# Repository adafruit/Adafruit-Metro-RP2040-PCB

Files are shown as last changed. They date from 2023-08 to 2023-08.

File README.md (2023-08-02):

## Adafruit Metro RP2040 PCB

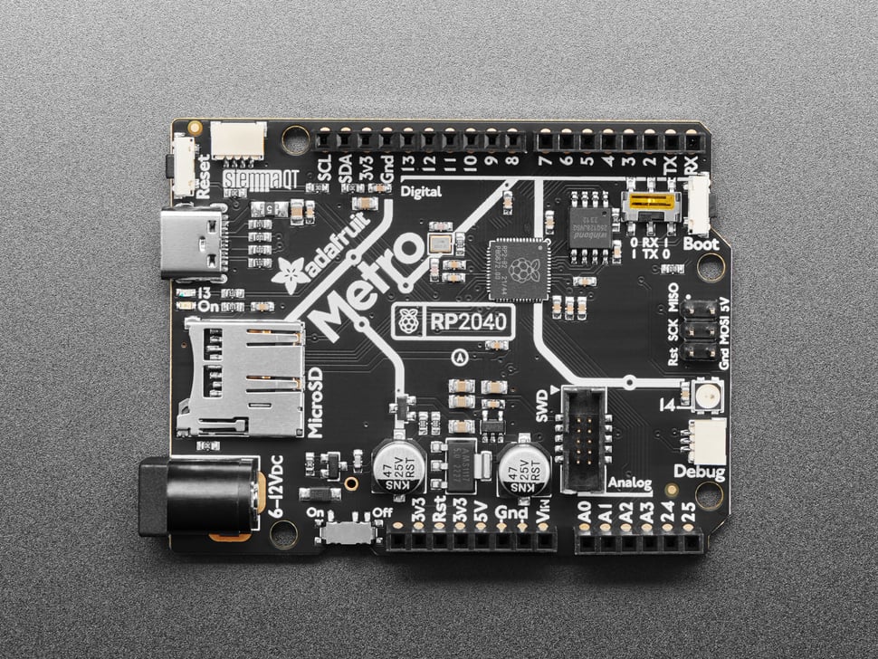
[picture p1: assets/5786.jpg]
<a href="http://www.adafruit.com/products/5786"><br/>
Click here to purchase one from the Adafruit shop</a>

PCB files for the Adafruit Metro RP2040. 

Format is EagleCAD schematic and board layout
* https://www.adafruit.com/product/5786

### Description

Choo! Choo! This is the RP2040 Metro Line, making all station stops at "Dual Cortex M0+ mountain", "264K RAM round-about" and "16 Megabytes of Flash town". This train is pile high with hardware that complements the Raspberry Pi RP2040 chip to make it an excellent development board for projects that want Arduino-shape-compatibility or just need the extra space and debugging ports.

* RP2040 main chip, 133MHz clock, 3.3V logic
* 16 MB of QSPI flash for program storage
* 24 GPIO, 4 of which are also analog inputs
* Micro SD card wired up for SPI interfacing, also has extra pins connected for advanced-user SDIO interfacing (note that there's no released usage code for SDIO in Arduino/Python, so this is a super-cutting-edge setup)
* Onboard RGB NeoPixel
* Onboard #13 LED
* Stemma QT port for I2C peripherals and sensors
* Reset and Boot buttons on PCB edge
* Pico Probe debug port - 3 pin JST SH compatible
* SWD debug port - 2x5 0.05" standard connector
* USB Type C power and data
* 5.5mm / 2.1mm DC jack for 6-12VDC power
* On/off switch for DC jack
* GPIO pin numbers match classic Arduino pins, other than A4/A5 which are D24 and D25 (there's only 4 ADC pins on the RP2040)
* RX / TX switch for swapping D0 and D1 locations

You may be wondering about the RX-TX switch: we added this because traditional Arduino board start counting the GPIO for the digital pins with 0-7 and then 8-13. However, the D0/D1 pins are also traditionally the hardware UART Serial1, where D0 is Rx and D1 is Tx. On the RP2040, however, the UART pins are the other around: D0 is Tx and D1 is Rx. Thus a DPDT switch: flip one way to have the GPIO go in order of 0-7, flip the other way to have the logical locations of the hardware UART correct but now the pin order is 1, 0, 2, 3..7. Of course, it's also handy if, like us, you often swap the pins - now you don't need to require or cut/solder traces!
About the RP2040

The RP2040 is a powerful chip, which has the clock speed of our M4 (SAMD51), and two cores that are equivalent to our M0 (SAMD21). Since it is an M0 chip, it does not have a floating point unit or DSP hardware support - so if you're doing something with heavy floating-point math, it will be done in software and thus not as fast as an M4. For many other computational tasks, you'll get close-to-M4 speeds!

For peripherals, there are two I2C controllers, two SPI controllers, and two UARTs that are multiplexed across the GPIO - check the pinout for what pins can be set to which. There are 16 PWM channels, each pin has a channel it can be set to (ditto on the pinout).

You'll note there's no I2S peripheral, or SDIO, or camera, what's up with that? Well, instead of having specific hardware support for serial-data-like peripherals like these, the RP2040 comes with the PIO state machine system, which is a unique and powerful way to create custom hardware logic and data processing blocks that run on their own without taking up a CPU. For example, NeoPixels - often we bitbang the timing-specific protocol for these LEDs. For the RP2040, we instead use PIO object that reads in the data buffer and clocks out the right bitstream with perfect accuracy. Same with I2S audio in or out, LED matrix displays, 8-bit or SPI based TFTs, even VGA! In MicroPython and CircuitPython, you can create PIO control commands to script the peripheral and load it in at runtime. There are 2 PIO peripherals with 4 state machines each.

There is great C/C++ support, unofficial (but really good) Arduino support, an official MicroPython port, and a CircuitPython port! We, of course, recommend CircuitPython because we think it's the easiest way to get started, and it has support with most of our drivers, displays, sensors, and more, supported out of the box so you can follow along with our CircuitPython projects and tutorials.

While the RP2040 has lots of onboard RAM (264KB), it does not have built-in FLASH memory. Instead, that is provided by the external QSPI flash chip. On this board, there is 16 MB, which is shared between the program it's running and any file storage used by MicroPython or CircuitPython. When using C/C++, you get the whole flash memory, if using Python, you will have about 7 MB remaining for code, files, images, fonts, etc.
RP2040 Chip features:

* Dual ARM Cortex-M0+ @ 133MHz
* 264kB on-chip SRAM in six independent banks
* Support for up to 16MB of off-chip Flash memory via dedicated QSPI bus
* DMA controller
* Fully-connected AHB crossbar
* Interpolator and integer divider peripherals
* On-chip programmable LDO to generate core voltage
* 2 on-chip PLLs to generate USB and core clocks
* 30 GPIO pins, 4 of which can be used as analog inputs
* Peripherals
  * 2 UARTs
  * 2 SPI controllers
  * 2 I2C controllers
  * 16 PWM channels
  * USB 1.1 controller and PHY, with host and device support
  * 8 PIO state machines

### License

Adafruit invests time and resources providing this open source design, please support Adafruit and open-source hardware by purchasing products from [Adafruit](https://www.adafruit.com)!

Designed by Limor Fried/Ladyada for Adafruit Industries.

Creative Commons Attribution/Share-Alike, all text above must be included in any redistribution. 
See license.txt for additional details.

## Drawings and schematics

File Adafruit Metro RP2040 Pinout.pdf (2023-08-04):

# Adafruit Metro RP2040

# https://www.adafruit.com/product/5786

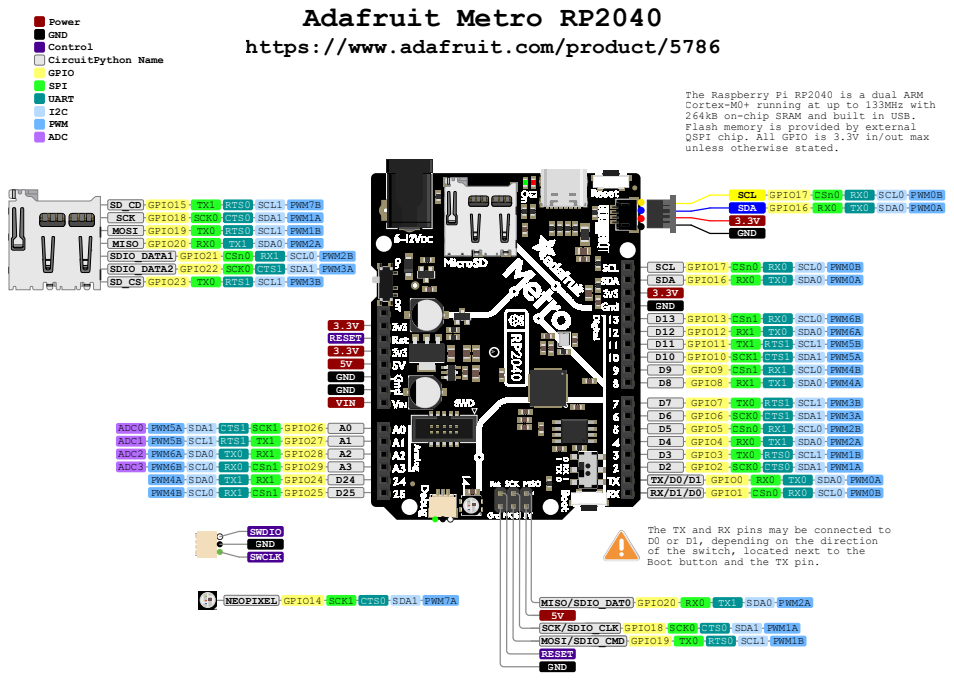
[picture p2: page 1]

The Raspberry Pi RP2040 is a dual ARM
Cortex-M0+ running at up to 133MHz with
264kB on-chip SRAM and built in USB.
Flash memory is provided by external
QSPI chip. All GPIO is 3.3V in/out max
unless otherwise stated.

The TX and RX pins may be connected to
D0 or D1, depending on the direction
of the switch, located next to the
Boot button and the TX pin.

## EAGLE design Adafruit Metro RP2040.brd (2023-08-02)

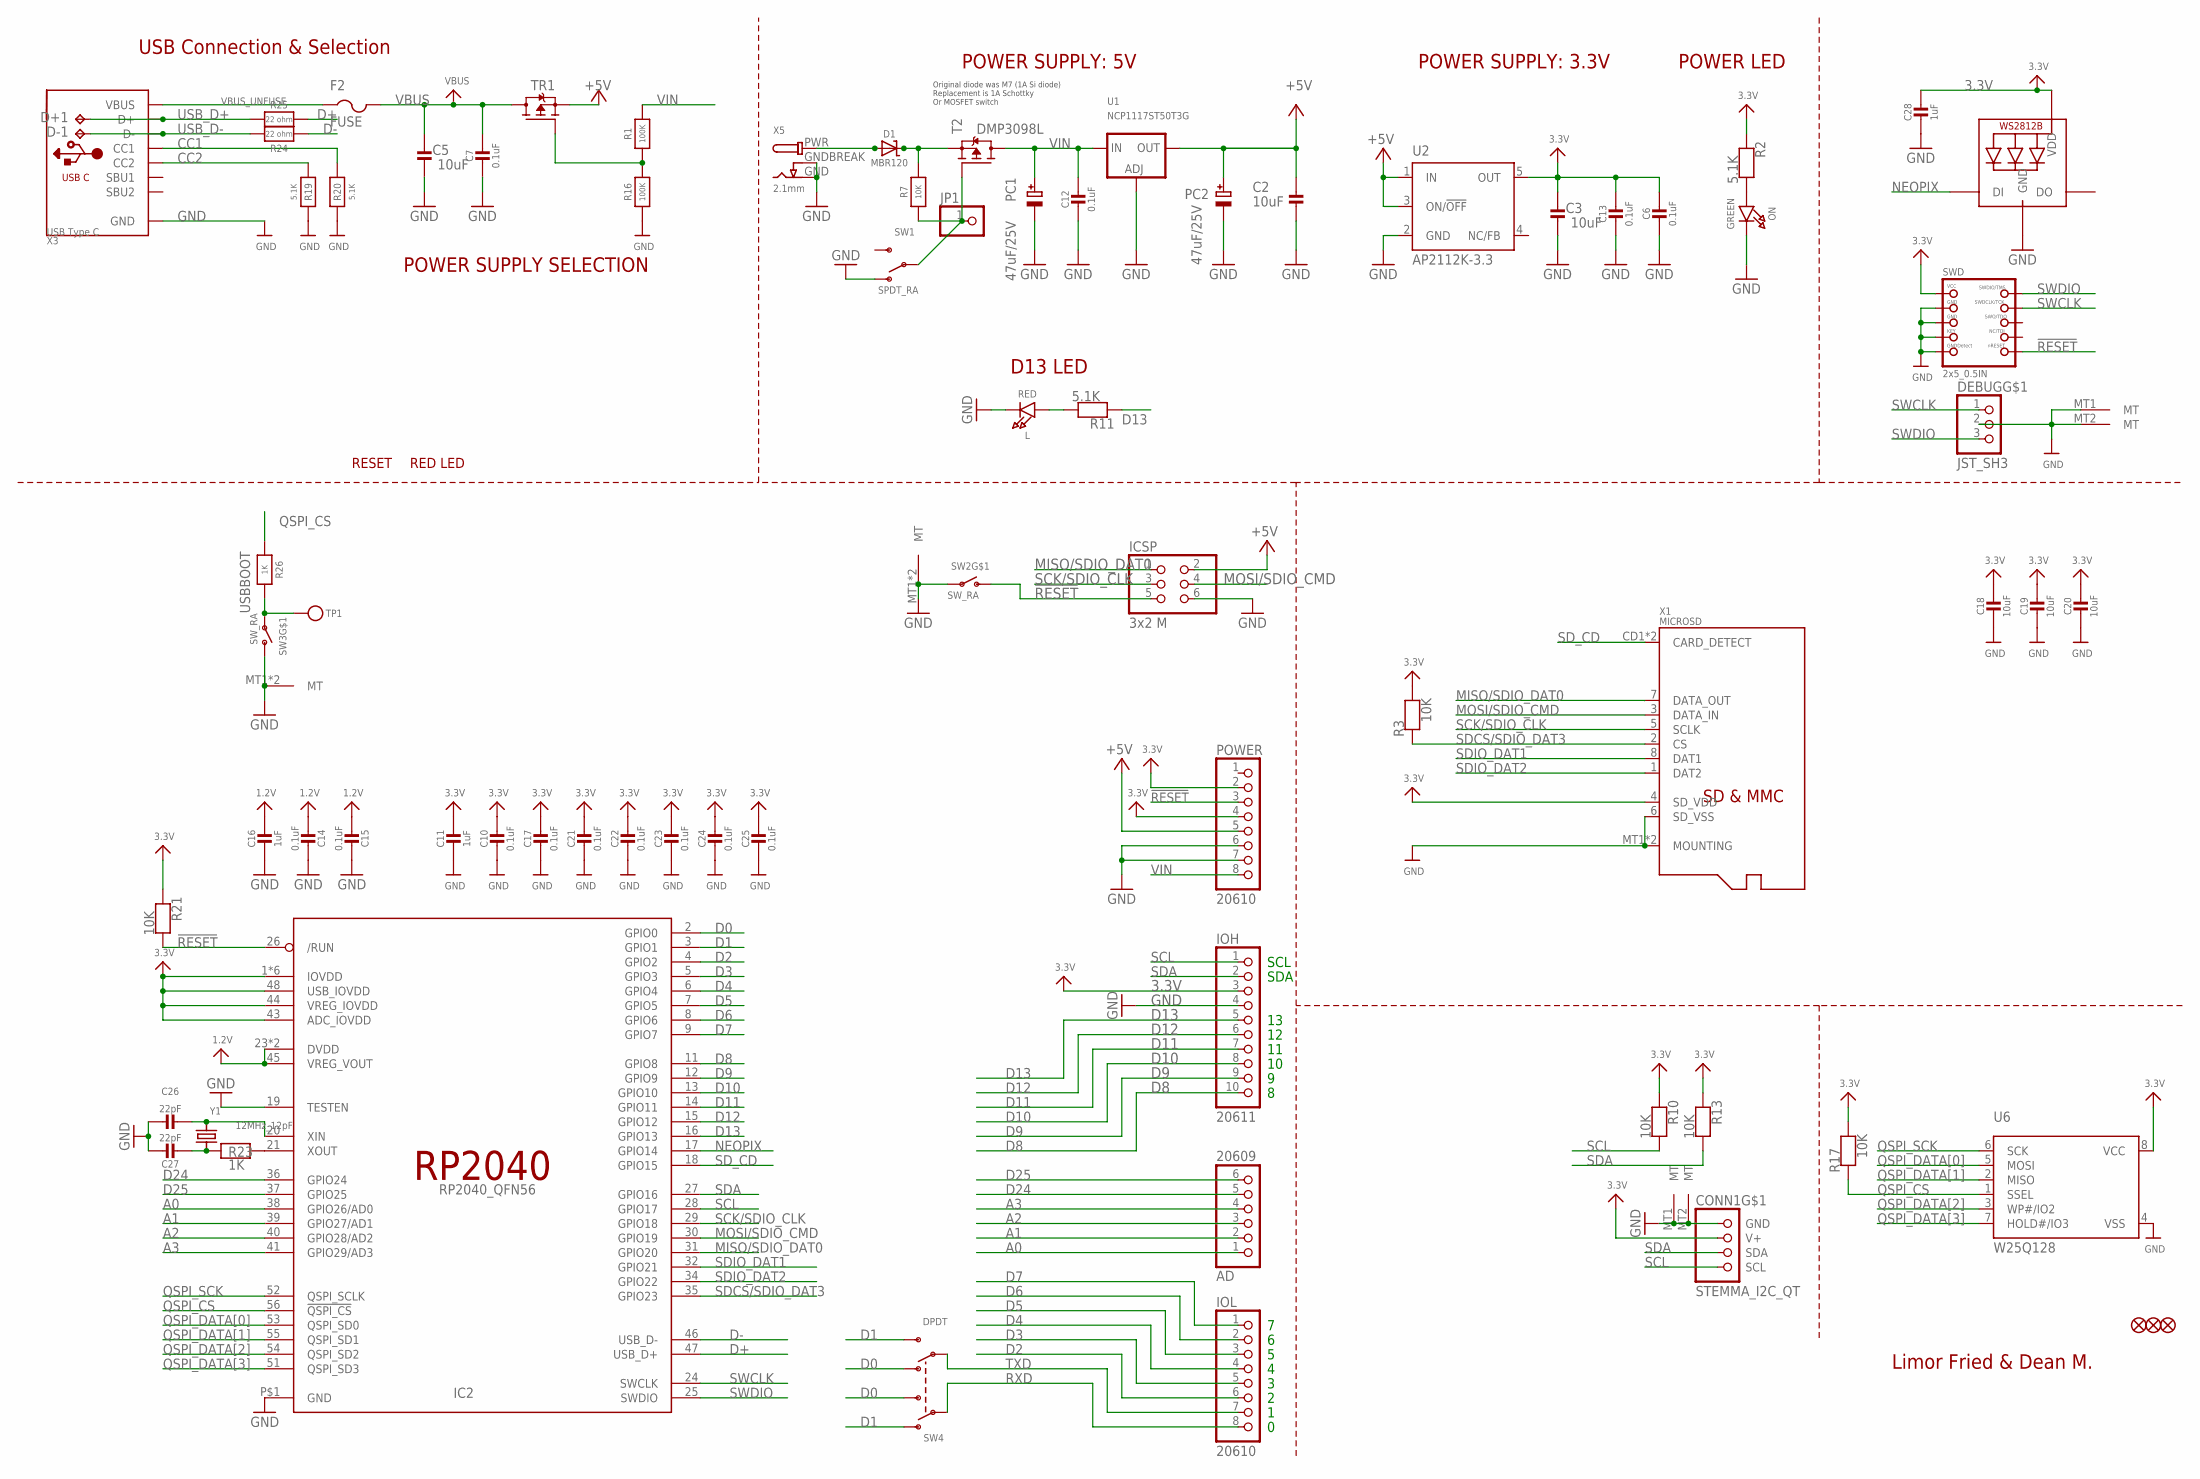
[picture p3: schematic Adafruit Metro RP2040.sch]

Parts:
AD: 20609; 1X06_OVALWAVE
C2, C3, C5, C18, C19, C20: 10uF; 0805-NO
C6, C7, C10, C12, C13, C14, C15, C17, C21, C22, C23, C24, C25: 0.1uF; 0603-NO
C11, C16, C28: 1uF; 0603-NO
C26, C27: 22pF; 0603-NO
CONN1: STEMMA_I2C_QT; JST_SH4
D1: MBR120; SOD-123
D+1: TPB1,27; B1,27
D-1: TPB1,27; B1,27
DEBUG: JST_SH3
F2: FUSE; R1206
FD1, FD2, FD3: FIDUCIAL_1MM
IC2: RP2040_QFN56; QFN56_7MM_REDUCEDEPAD
ICSP: 3x2 M; 2X03_ROUND_70MIL
IOH: 20611; 1X10_OVALWAVE
IOL: 20610; 1X08_OVALWAVE
JP1: HEADER-1X1ROUND; 1X01_ROUND
L: RED; CHIPLED_0603_NOOUTLINE
LED2: WS2812B_3535FULL; LED3535_FULLPADS
ON: GREEN; CHIPLED_0603_NOOUTLINE
PC1, PC2: 47uF/25V; PANASONIC_D
POWER: 20610; 1X08_OVALWAVE
R1, R16: 100K; 0603-NO
R2, R11, R19, R20: 5.1K; 0603-NO
R3, R7, R10, R13, R17, R21: 10K; 0603-NO
R23, R26: 1K; 0603-NO
R24, R25: 22 ohm; 0603-NO
SW1: SPDT_RA; SPDT_SMT_SSSS811101
SW2, SW3: SW_RA; SPST_TACTILE_RA
SW4: DPDT; EG1390
SWD: 2x5_0.5IN; 2X05_1.27MM_BOX_POSTS
T2: DMP3098L; SOT23-WIDE
TP1: TESTPOINTROUND1.5MMNO; TESTPOINT_ROUND_1.5MM_NO
TR1: DMP3098L; SOT23-WIDE
U1: NCP1117ST50T3G; SOT223-R
U2: AP2112K-3.3; SOT23-DBV
U6: W25Q128; SOIC8_208MIL
X1: MICROSD
X3: USB Type C; USB_C_CUSB31-CFM2AX-01-X
X5: 2.1mm; DCJACK_2MM_PTH
Y1: 12MHz_12pF; CRYSTAL_2.5X2

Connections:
1.2V: C14.2, C15.2, C16.1, IC2.23 (DVDD), IC2.45 (VREG_VOUT), IC2.50 (DVDD)
3.3V: C3.2, C6.2, C10.1, C11.1, C13.1, C17.1, C18.1, C19.1, C20.1, C21.1, C22.1, C23.1, C24.1, C25.1, C28.1, CONN1.2 (V+), IC2.1 (IOVDD), IC2.10 (IOVDD), IC2.22 (IOVDD), IC2.33 (IOVDD), IC2.42 (IOVDD), IC2.43 (ADC_IOVDD), IC2.44 (VREG_IOVDD), IC2.48 (USB_IOVDD), IC2.49 (IOVDD), IOH.3, LED2.2 (VDD), POWER.2, POWER.4, R2.1, R3.2, R10.1, R13.1, R17.2, R21.1, SWD.1 (VCC), U2.5 (OUT), U6.8 (VCC), X1.4 (SD_VDD)
!RESET: IC2.26 (/RUN), ICSP.5, POWER.3, R21.2, SW2.2 (S), SWD.10 (NRESET)
+5V: C2.2, ICSP.2, PC2.+, POWER.5, TR1.2 (S), U1.2 (OUT), U1.4 (OUT), U2.1 (IN), U2.3 (ON/!OFF)
A0: AD.1, IC2.38 (GPIO26/AD0)
A1: AD.2, IC2.39 (GPIO27/AD1)
A2: AD.3, IC2.40 (GPIO28/AD2)
A3: AD.4, IC2.41 (GPIO29/AD3)
CC1: R20.2, X3.A5 (CC1)
CC2: R19.2, X3.B5 (CC2)
D0: IC2.2 (GPIO0), SW4.O2, SW4.S1
D1: IC2.3 (GPIO1), SW4.O1, SW4.S2
D2: IC2.4 (GPIO2), IOL.6
D3: IC2.5 (GPIO3), IOL.5
D4: IC2.6 (GPIO4), IOL.4
D5: IC2.7 (GPIO5), IOL.3
D6: IC2.8 (GPIO6), IOL.2
D7: IC2.9 (GPIO7), IOL.1
D8: IC2.11 (GPIO8), IOH.10
D9: IC2.12 (GPIO9), IOH.9
D10: IC2.13 (GPIO10), IOH.8
D11: IC2.14 (GPIO11), IOH.7
D12: IC2.15 (GPIO12), IOH.6
D13: IC2.16 (GPIO13), IOH.5, R11.1
D24: AD.5, IC2.36 (GPIO24)
D25: AD.6, IC2.37 (GPIO25)
D+: IC2.47 (USB_D+), R25.2
D-: IC2.46 (USB_D-), R24.2
GND: C2.1, C3.1, C5.1, C6.1, C7.2, C10.2, C11.2, C12.2, C13.2, C14.1, C15.1, C16.2, C17.2, C18.2, C19.2, C20.2, C21.2, C22.2, C23.2, C24.2, C25.2, C26.1, C27.1, C28.2, CONN1.1 (GND), CONN1.MT1 (MT), CONN1.MT2 (MT), DEBUG.2, DEBUG.MT1 (MT), DEBUG.MT2 (MT), IC2.19 (TESTEN), IC2.P$1 (GND), ICSP.6, IOH.4, L.C, LED2.4 (GND), ON.C, PC1.-, PC2.-, POWER.6, POWER.7, R16.1, R19.1, R20.1, SW1.A (O), SW2.1, SW2.MT1 (MT), SW2.MT2 (MT), SW3.2 (S), SW3.MT1 (MT), SW3.MT2 (MT), SWD.3 (GND), SWD.5 (GND), SWD.7 (KEY), SWD.9 (GNDDETECT), U1.1 (ADJ), U2.2 (GND), U6.4 (VSS), X1.6 (SD_VSS), X1.MT1 (MOUNTING), X1.MT2 (MOUNTING), X3.A1B12 (GND), X3.B1A12 (GND), X5.GND, X5.GNDBREAK
MISO/SDIO_DAT0: IC2.31 (GPIO20), ICSP.1, X1.7 (DATA_OUT)
MOSI/SDIO_CMD: IC2.30 (GPIO19), ICSP.4, X1.3 (DATA_IN)
unnamed: L.A, R11.2
unnamed: ON.A, R2.2
unnamed: C26.2, IC2.20 (XIN), Y1.3 (2)
unnamed: C27.2, R23.1, Y1.1
unnamed: R1.1, R16.2, TR1.1 (G)
unnamed: IC2.21 (XOUT), R23.2
unnamed: D1.C, R7.2, T2.2 (S)
NEOPIX: IC2.17 (GPIO14), LED2.1 (DI)
PWRIN: D1.A, X5.PWR
PWR_SWITCH: JP1.1, R7.1, SW1.B, T2.1 (G)
QSPI_CS: IC2.56 (!QSPI_CS), R17.1, R26.1, U6.1 (SSEL)
QSPI_DATA[0]: IC2.53 (QSPI_SD0), U6.5 (MOSI)
QSPI_DATA[1]: IC2.55 (QSPI_SD1), U6.2 (MISO)
QSPI_DATA[2]: IC2.54 (QSPI_SD2), U6.3 (WP#/IO2)
QSPI_DATA[3]: IC2.51 (QSPI_SD3), U6.7 (HOLD#/IO3)
QSPI_SCK: IC2.52 (QSPI_SCLK), U6.6 (SCK)
RXD: IOL.8, SW4.P1
SCK/SDIO_CLK: IC2.29 (GPIO18), ICSP.3, X1.5 (SCLK)
SCL: CONN1.4 (SCL), IC2.28 (GPIO17), IOH.1, R10.2
SDA: CONN1.3 (SDA), IC2.27 (GPIO16), IOH.2, R13.2
SDCS/SDIO_DAT3: IC2.35 (GPIO23), R3.1, X1.2 (CS)
SDIO_DAT1: IC2.32 (GPIO21), X1.8 (DAT1)
SDIO_DAT2: IC2.34 (GPIO22), X1.1 (DAT2)
SD_CD: IC2.18 (GPIO15), X1.CD1 (CARD_DETECT), X1.CD2 (CARD_DETECT)
SWCLK: DEBUG.1, IC2.24 (SWCLK), SWD.4 (SWDCLK)
SWDIO: DEBUG.3, IC2.25 (SWDIO), SWD.2 (SWDIO)
TXD: IOL.7, SW4.P2
USBBOOT: R26.2, SW3.1, TP1.P$1
USB_D+: D+1.TP, R25.1, X3.A6 (D+), X3.B6 (D+)
USB_D-: D-1.TP, R24.1, X3.A7 (D-), X3.B7 (D-)
VBUS: C5.2, C7.1, F2.2, TR1.3 (D)
VBUS_UNFUSE: F2.1, X3.A4B9 (VBUS), X3.B4A9 (VBUS)
VIN: C12.1, PC1.+, POWER.8, R1.2, T2.3 (D), U1.3 (IN)

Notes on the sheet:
SDA
SCL
Limor Fried & Dean M.
Original diode was M7 (1A Si diode) Replacement is 1A Schottky Or MOSFET switch
POWER SUPPLY: 5V
USB Connection & Selection
POWER SUPPLY: 3.3V
POWER LED
POWER SUPPLY SELECTION
D13 LED
RESET
RED LED

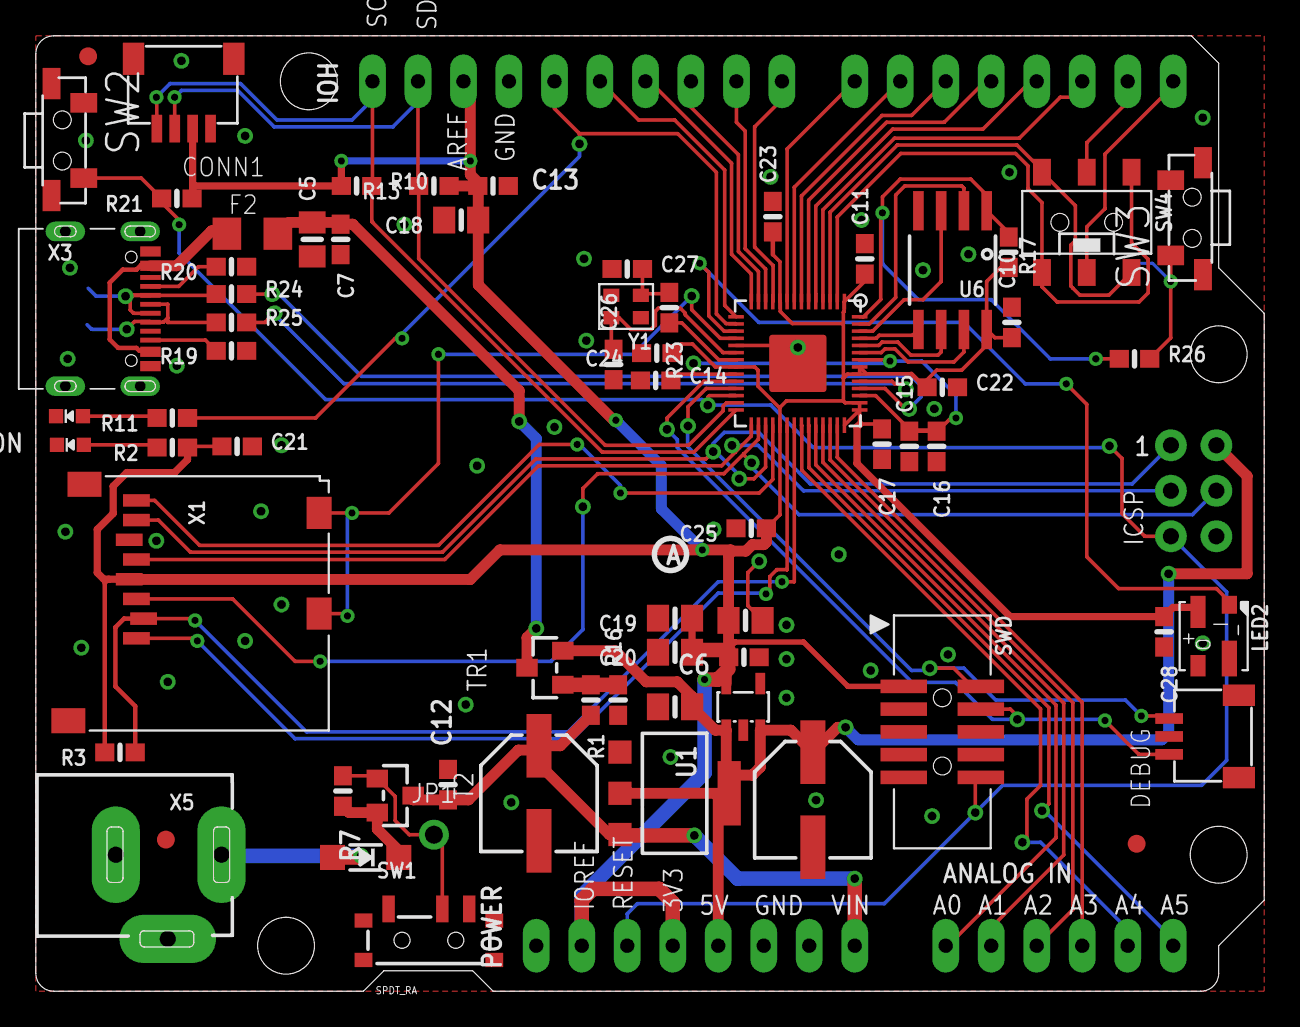
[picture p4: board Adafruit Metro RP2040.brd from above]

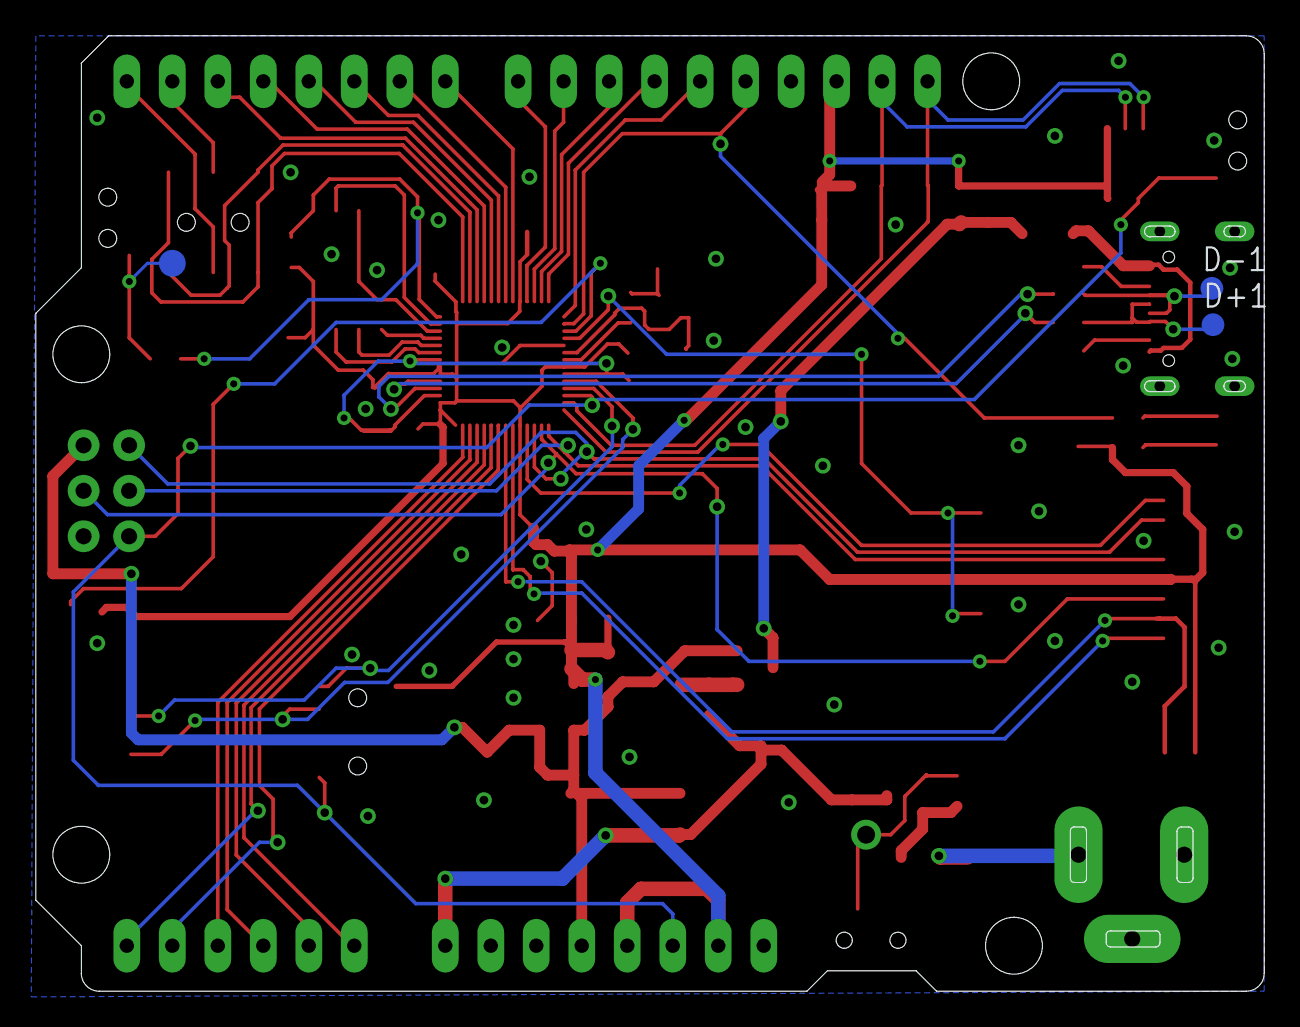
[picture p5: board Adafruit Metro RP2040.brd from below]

Board: 2 copper layers, 68.6 x 53.3 mm, 79 parts (4 on the bottom side), 64 nets.

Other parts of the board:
U$11: PCBFEAT-REV-040
U$15: METRO_RP2040_BOT
U$29: METRO_RP2040_TOP

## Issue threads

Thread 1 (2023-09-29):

SPI1 CS and SCK pins switched from UNO SPI layout

ZedOud, 2023-09-29:
I hope this is the appropriate place to submit this issue concerning the layout of the board's pins.

I may be misunderstanding and underestimating the flexibility of reassigning pins to use SPI1 as mentioned in the [arduino-pico documentation](https://arduino-pico.readthedocs.io/en/latest/spi.html).

However, it seems to me that pins 10 and 13 should be switched on this board in order for SPI1 to match the original SPI pinout of the UNO. I'm not sure any UNO shield reliant on SPI will work unless SPI1.setCS and SPI1.setCLK can indeed be used to swap 10 and 13.
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

Metro RP2040 pins 10-13:
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

I had a different [pico adaptor board](https://lectronz.com/products/raspberry-pi-pico-to-uno-flexypin-adapter) and used it to test that indeed, a RP2040 can drive my shield on SPI (SPI0 that is).

It's possible (and indeed very likely) that there is some nuance to the use of the philhower core and its implementation of SPI1 that is preventing the method mentioned in the documentation from working owing to my own misunderstanding, so I've provided example code (based on some googling and my understanding of the documentation) of setting up SPI1 in a manner to fix this pin swap issue.

```C++
#include <SPI.h>

#define spi1_SCK 13 // The shield needs SCK on 13 because of the UNO pinout
#define spi1_MISO 12
#define spi1_MOSI 11
#define nCS_PIN 10 // The shield needs CS on 10 because of the UNO pinout

powerSTEP driver(0, nCS_PIN, nSTBY_nRESET_PIN);

void setup() {

  // Prepare pins
  pinMode(nCS_PIN, OUTPUT);
  pinMode(spi1_MOSI, OUTPUT);
  pinMode(spi1_MISO, OUTPUT);
  pinMode(spi1_SCK, OUTPUT);

  SPI1.setRX(spi1_MISO);
  SPI1.setTX(spi1_MOSI);
  SPI1.setSCK(spi1_SCK);
  SPI1.setCS(nCS_PIN);

  // Start SPI
  SPI1.begin();
  SPI1.setDataMode(SPI_MODE3);

  driver.SPIPortConnect(&SPI1);
// ...
}
// ...
```

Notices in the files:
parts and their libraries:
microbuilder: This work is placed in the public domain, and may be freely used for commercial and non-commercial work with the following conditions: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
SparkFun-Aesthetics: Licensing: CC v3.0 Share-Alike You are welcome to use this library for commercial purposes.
